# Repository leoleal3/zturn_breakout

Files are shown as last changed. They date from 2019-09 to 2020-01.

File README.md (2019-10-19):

# zturn_breakout
A custom breakout board for the MYIR Z-Turn single board computer

### v1.0 - Full Breakout Board for Z-Turn
Status: Complete!   
Dimensions: 5.2"x4.5"   
Board Features:  
* 9 2x6 PMOD connectors
* 1 1x6 PMOD connector
* 2mm JTAG connector

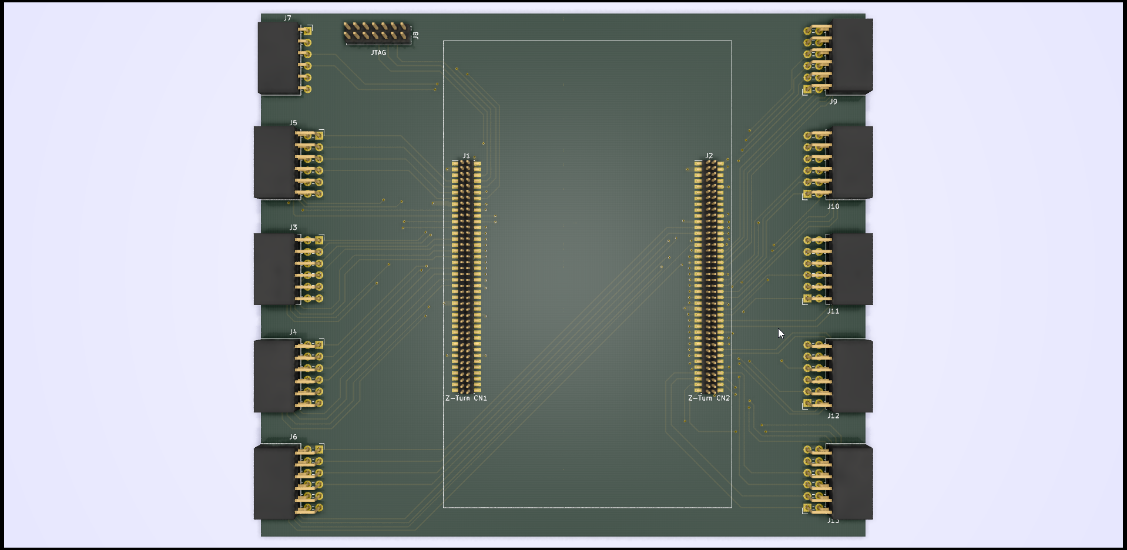
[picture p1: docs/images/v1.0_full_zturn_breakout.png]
KiCAD Render of Full Breakout Board


### v0.1 - Digilent HS3 JTAG Cable Adapter (2.54mm to 2mm)
Status: Complete!   
This is a simple 2.54mm to 2mm connector adapter to allow the use of the much cheaper [HS3 JTAG cable from Digilent](https://store.digilentinc.com/jtag-hs3-programming-cable/)

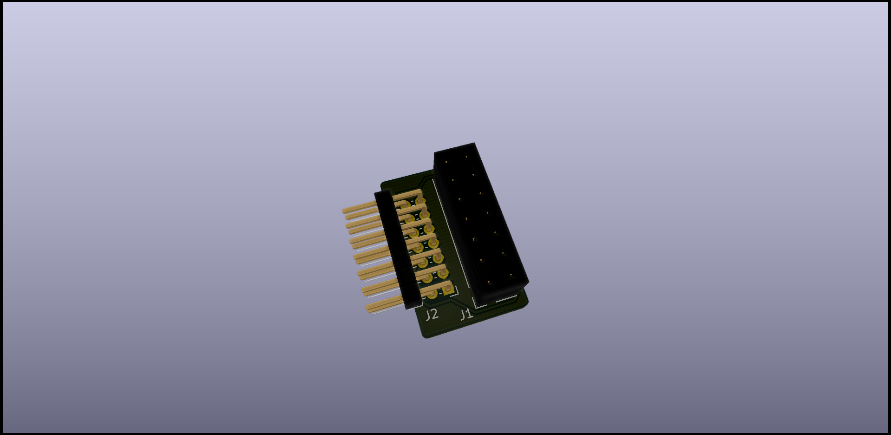
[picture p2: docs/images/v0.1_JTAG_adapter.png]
KiCAD Render of JTAG Adapter


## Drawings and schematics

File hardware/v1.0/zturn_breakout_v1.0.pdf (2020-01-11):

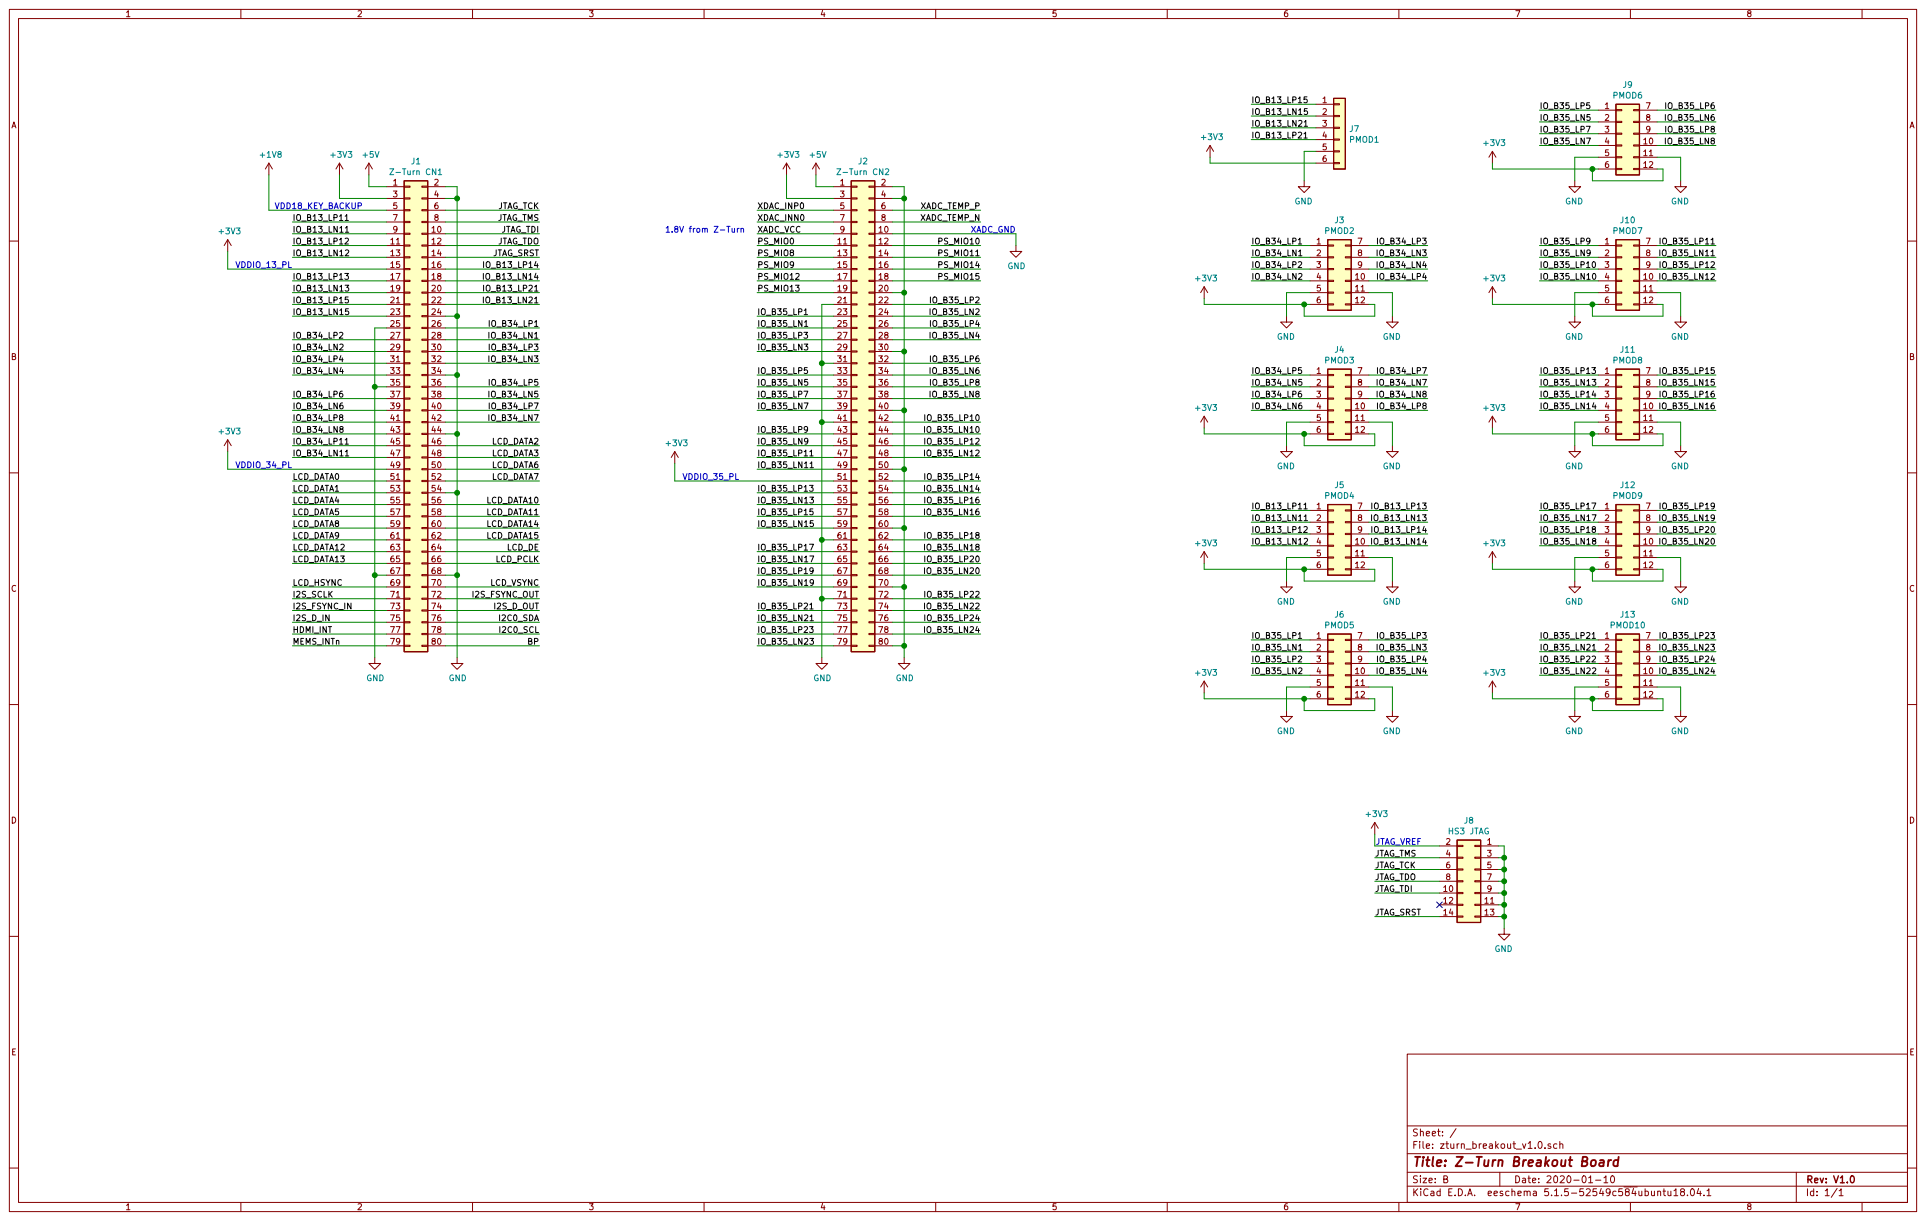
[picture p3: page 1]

File: zturn_breakout_v1.0.sch Sheet: /
Id: 1/1 Title: Z-Turn Breakout Board

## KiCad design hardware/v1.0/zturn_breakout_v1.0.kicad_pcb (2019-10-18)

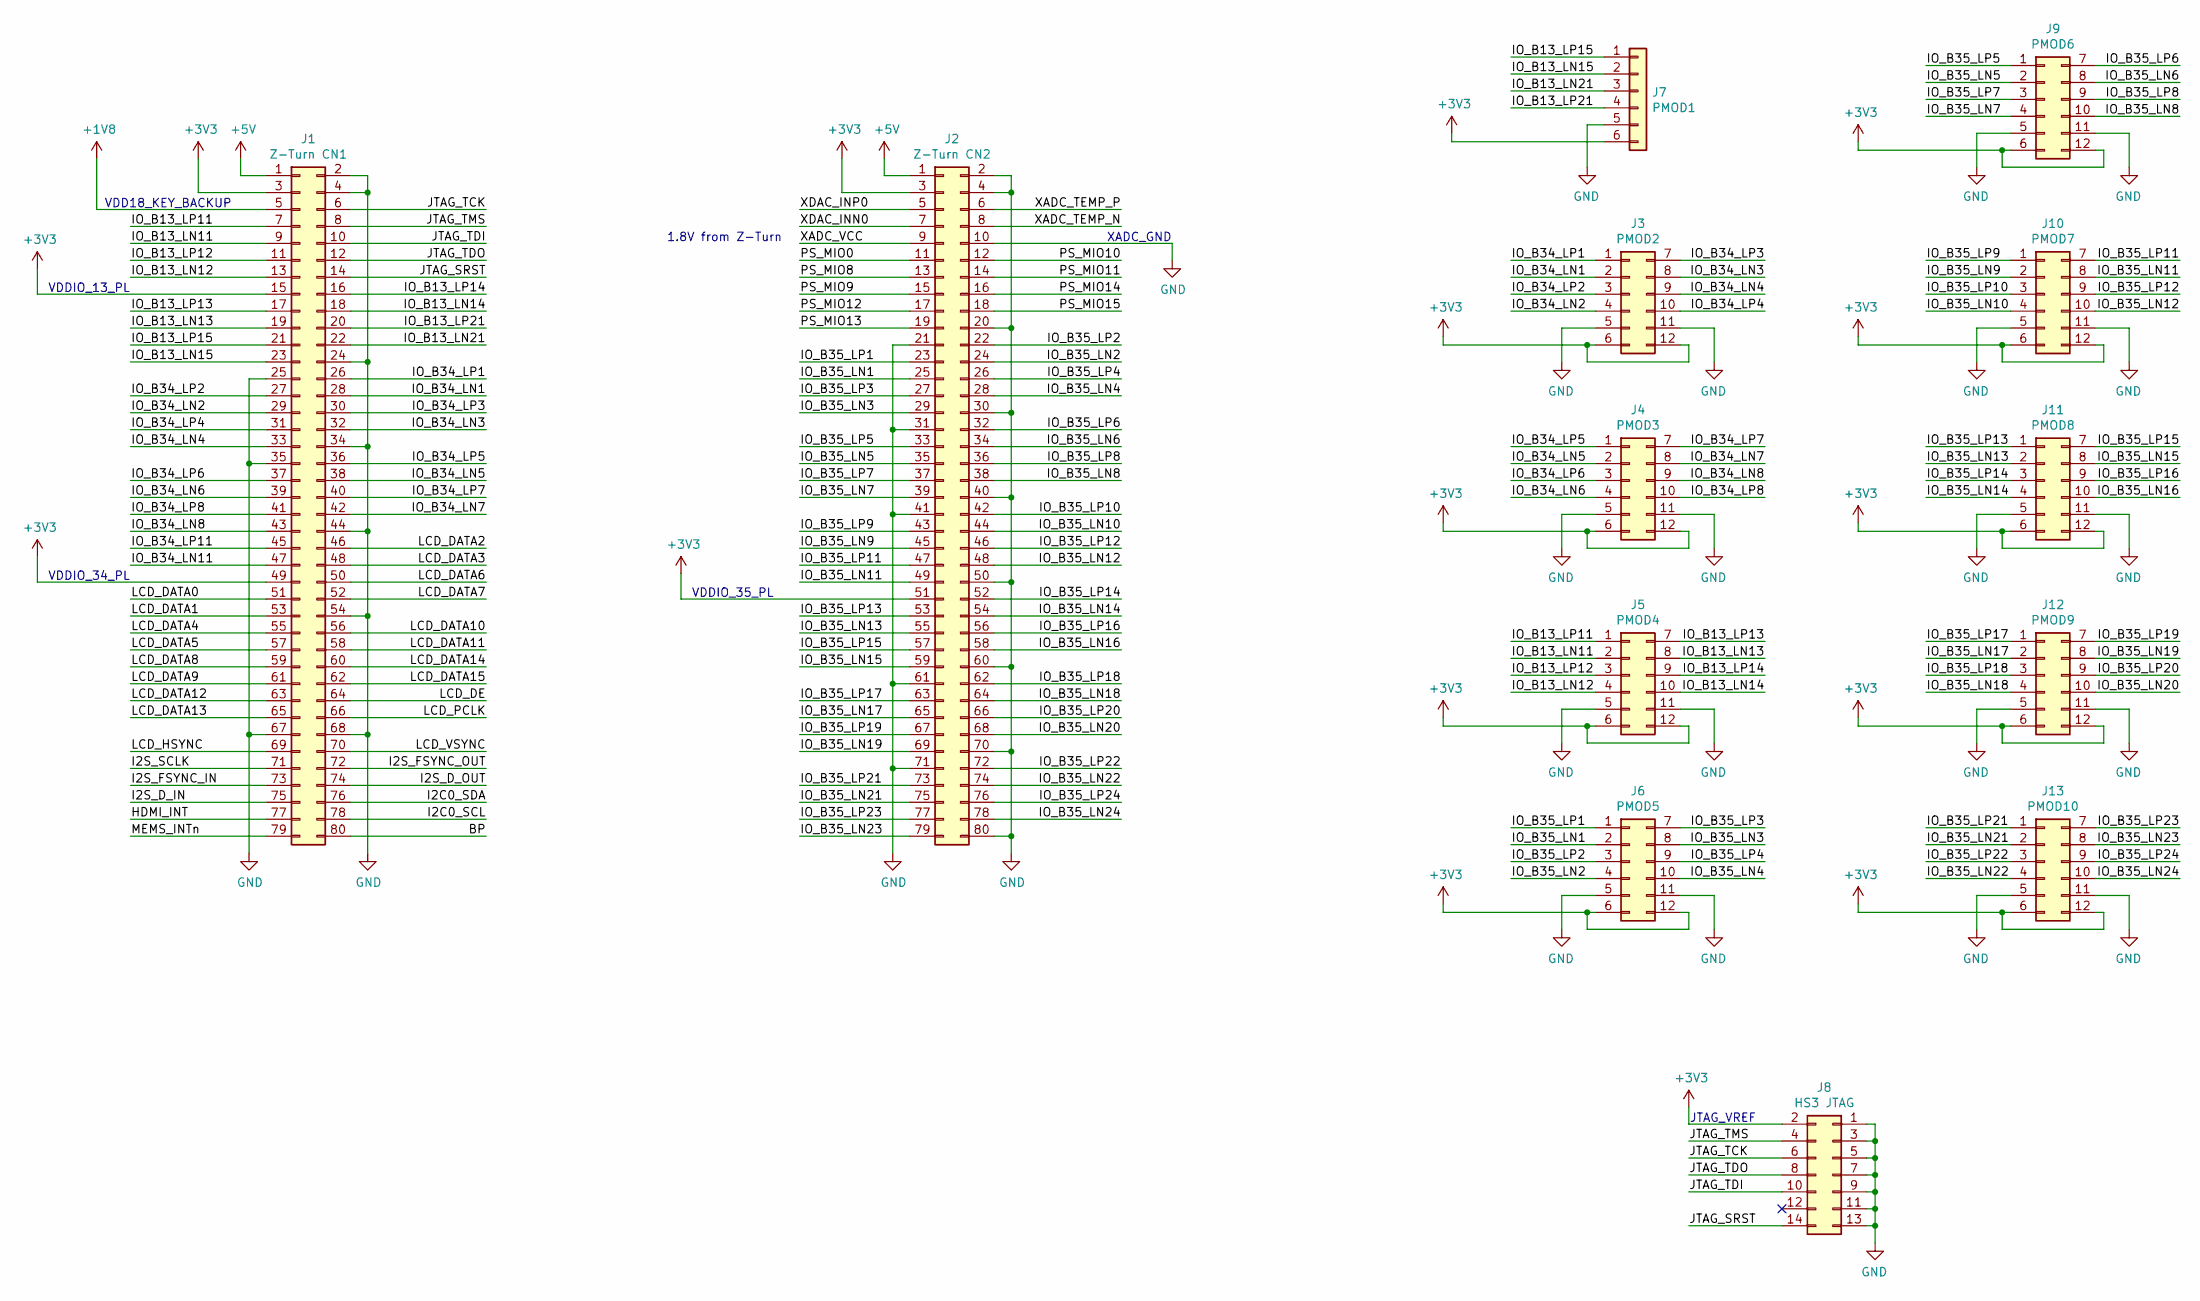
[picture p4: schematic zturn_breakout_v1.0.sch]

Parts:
J1: Z-Turn CN1; PinHeader_2x40_P1.27mm_Vertical_SMD; MPN 20021111-00080T4LF
J2: Z-Turn CN2; PinHeader_2x40_P1.27mm_Vertical_SMD; MPN 20021111-00080T4LF
J3: PMOD2; PinSocket_2x06_P2.54mm_Horizontal
J4: PMOD3; PinSocket_2x06_P2.54mm_Horizontal
J5: PMOD4; PinSocket_2x06_P2.54mm_Horizontal
J6: PMOD5; PinSocket_2x06_P2.54mm_Horizontal
J7: PMOD1; PinSocket_1x06_P2.54mm_Horizontal
J8: HS3 JTAG; PinHeader_2x07_P2.00mm_Vertical
J9: PMOD6; PinSocket_2x06_P2.54mm_Horizontal
J10: PMOD7; PinSocket_2x06_P2.54mm_Horizontal
J11: PMOD8; PinSocket_2x06_P2.54mm_Horizontal
J12: PMOD9; PinSocket_2x06_P2.54mm_Horizontal
J13: PMOD10; PinSocket_2x06_P2.54mm_Horizontal

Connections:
+1V8: J1.5
+3V3: J1.3, J1.15, J1.49, J2.3, J2.51, J3.6, J3.12, J4.6, J4.12, J5.6, J5.12, J6.6, J6.12, J7.6, J8.2, J9.6, J9.12, J10.6, J10.12, J11.6, J11.12, J12.6, J12.12, J13.6, J13.12
+5V: J1.1, J2.1
/BP: J1.80
/HDMI_INT: J1.77
/I2C0_SCL: J1.78
/I2C0_SDA: J1.76
/I2S_D_IN: J1.75
/I2S_D_OUT: J1.74
/I2S_FSYNC_IN: J1.73
/I2S_FSYNC_OUT: J1.72
/I2S_SCLK: J1.71
/IO_B13_LN11: J1.9, J5.2
/IO_B13_LN12: J1.13, J5.4
/IO_B13_LN13: J1.19, J5.8
/IO_B13_LN14: J1.18, J5.10
/IO_B13_LN15: J1.23, J7.2
/IO_B13_LN21: J1.22, J7.3
/IO_B13_LP11: J1.7, J5.1
/IO_B13_LP12: J1.11, J5.3
/IO_B13_LP13: J1.17, J5.7
/IO_B13_LP14: J1.16, J5.9
/IO_B13_LP15: J1.21, J7.1
/IO_B13_LP21: J1.20, J7.4
/IO_B34_LN1: J1.28, J3.2
/IO_B34_LN2: J1.29, J3.4
/IO_B34_LN3: J1.32, J3.8
/IO_B34_LN4: J1.33, J3.9
/IO_B34_LN5: J1.38, J4.2
/IO_B34_LN6: J1.39, J4.4
/IO_B34_LN7: J1.42, J4.8
/IO_B34_LN8: J1.43, J4.9
/IO_B34_LN11: J1.47
/IO_B34_LP1: J1.26, J3.1
/IO_B34_LP2: J1.27, J3.3
/IO_B34_LP3: J1.30, J3.7
/IO_B34_LP4: J1.31, J3.10
/IO_B34_LP5: J1.36, J4.1
/IO_B34_LP6: J1.37, J4.3
/IO_B34_LP7: J1.40, J4.7
/IO_B34_LP8: J1.41, J4.10
/IO_B34_LP11: J1.45
/IO_B35_LN1: J2.25, J6.2
/IO_B35_LN2: J2.24, J6.4
/IO_B35_LN3: J2.29, J6.8
/IO_B35_LN4: J2.28, J6.10
/IO_B35_LN5: J2.35, J9.2
/IO_B35_LN6: J2.34, J9.8
/IO_B35_LN7: J2.39, J9.4
/IO_B35_LN8: J2.38, J9.10
/IO_B35_LN9: J2.45, J10.2
/IO_B35_LN10: J2.44, J10.4
/IO_B35_LN11: J2.49, J10.8
/IO_B35_LN12: J2.48, J10.10
/IO_B35_LN13: J2.55, J11.2
/IO_B35_LN14: J2.54, J11.4
/IO_B35_LN15: J2.59, J11.8
/IO_B35_LN16: J2.58, J11.10
/IO_B35_LN17: J2.65, J12.2
/IO_B35_LN18: J2.64, J12.4
/IO_B35_LN19: J2.69, J12.8
/IO_B35_LN20: J2.68, J12.10
/IO_B35_LN21: J2.75, J13.2
/IO_B35_LN22: J2.74, J13.4
/IO_B35_LN23: J2.79, J13.8
/IO_B35_LN24: J2.78, J13.10
/IO_B35_LP1: J2.23, J6.1
/IO_B35_LP2: J2.22, J6.3
/IO_B35_LP3: J2.27, J6.7
/IO_B35_LP4: J2.26, J6.9
/IO_B35_LP5: J2.33, J9.1
/IO_B35_LP6: J2.32, J9.7
/IO_B35_LP7: J2.37, J9.3
/IO_B35_LP8: J2.36, J9.9
/IO_B35_LP9: J2.43, J10.1
/IO_B35_LP10: J2.42, J10.3
/IO_B35_LP11: J2.47, J10.7
/IO_B35_LP12: J2.46, J10.9
/IO_B35_LP13: J2.53, J11.1
/IO_B35_LP14: J2.52, J11.3
/IO_B35_LP15: J2.57, J11.7
/IO_B35_LP16: J2.56, J11.9
/IO_B35_LP17: J2.63, J12.1
/IO_B35_LP18: J2.62, J12.3
/IO_B35_LP19: J2.67, J12.7
/IO_B35_LP20: J2.66, J12.9
/IO_B35_LP21: J2.73, J13.1
/IO_B35_LP22: J2.72, J13.3
/IO_B35_LP23: J2.77, J13.7
/IO_B35_LP24: J2.76, J13.9
/JTAG_SRST: J1.14, J8.14
/JTAG_TCK: J1.6, J8.6
/JTAG_TDI: J1.10, J8.10
/JTAG_TDO: J1.12, J8.8
/JTAG_TMS: J1.8, J8.4
/LCD_DATA0: J1.51
/LCD_DATA1: J1.53
/LCD_DATA2: J1.46
/LCD_DATA3: J1.48
/LCD_DATA4: J1.55
/LCD_DATA5: J1.57
/LCD_DATA6: J1.50
/LCD_DATA7: J1.52
/LCD_DATA8: J1.59
/LCD_DATA9: J1.61
/LCD_DATA10: J1.56
/LCD_DATA11: J1.58
/LCD_DATA12: J1.63
/LCD_DATA13: J1.65
/LCD_DATA14: J1.60
/LCD_DATA15: J1.62
/LCD_DE: J1.64
/LCD_HSYNC: J1.69
/LCD_PCLK: J1.66
/LCD_VSYNC: J1.70
/MEMS_INTn: J1.79
/PS_MIO0: J2.11
/PS_MIO8: J2.13
/PS_MIO9: J2.15
/PS_MIO10: J2.12
/PS_MIO11: J2.14
/PS_MIO12: J2.17
/PS_MIO13: J2.19
/PS_MIO14: J2.16
/PS_MIO15: J2.18
/XADC_TEMP_N: J2.8
/XADC_TEMP_P: J2.6
/XADC_VCC: J2.9
/XDAC_INN0: J2.7
/XDAC_INP0: J2.5
GND: J1.2, J1.4, J1.24, J1.25, J1.34, J1.35, J1.44, J1.54, J1.67, J1.68, J2.2, J2.4, J2.10, J2.20, J2.21, J2.30, J2.31, J2.40, J2.41, J2.50, J2.60, J2.61, J2.70, J2.71, J2.80, J3.5, J3.11, J4.5, J4.11, J5.5, J5.11, J6.5, J6.11, J7.5, J8.1, J8.3, J8.5, J8.7, J8.9, J8.11, J8.13, J9.5, J9.11, J10.5, J10.11, J11.5, J11.11, J12.5, J12.11, J13.5, J13.11

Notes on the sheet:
XADC_GND
VDDIO_13_PL
VDDIO_34_PL
VDDIO_35_PL
VDD18_KEY_BACKUP
1.8V from Z-Turn
JTAG_VREF

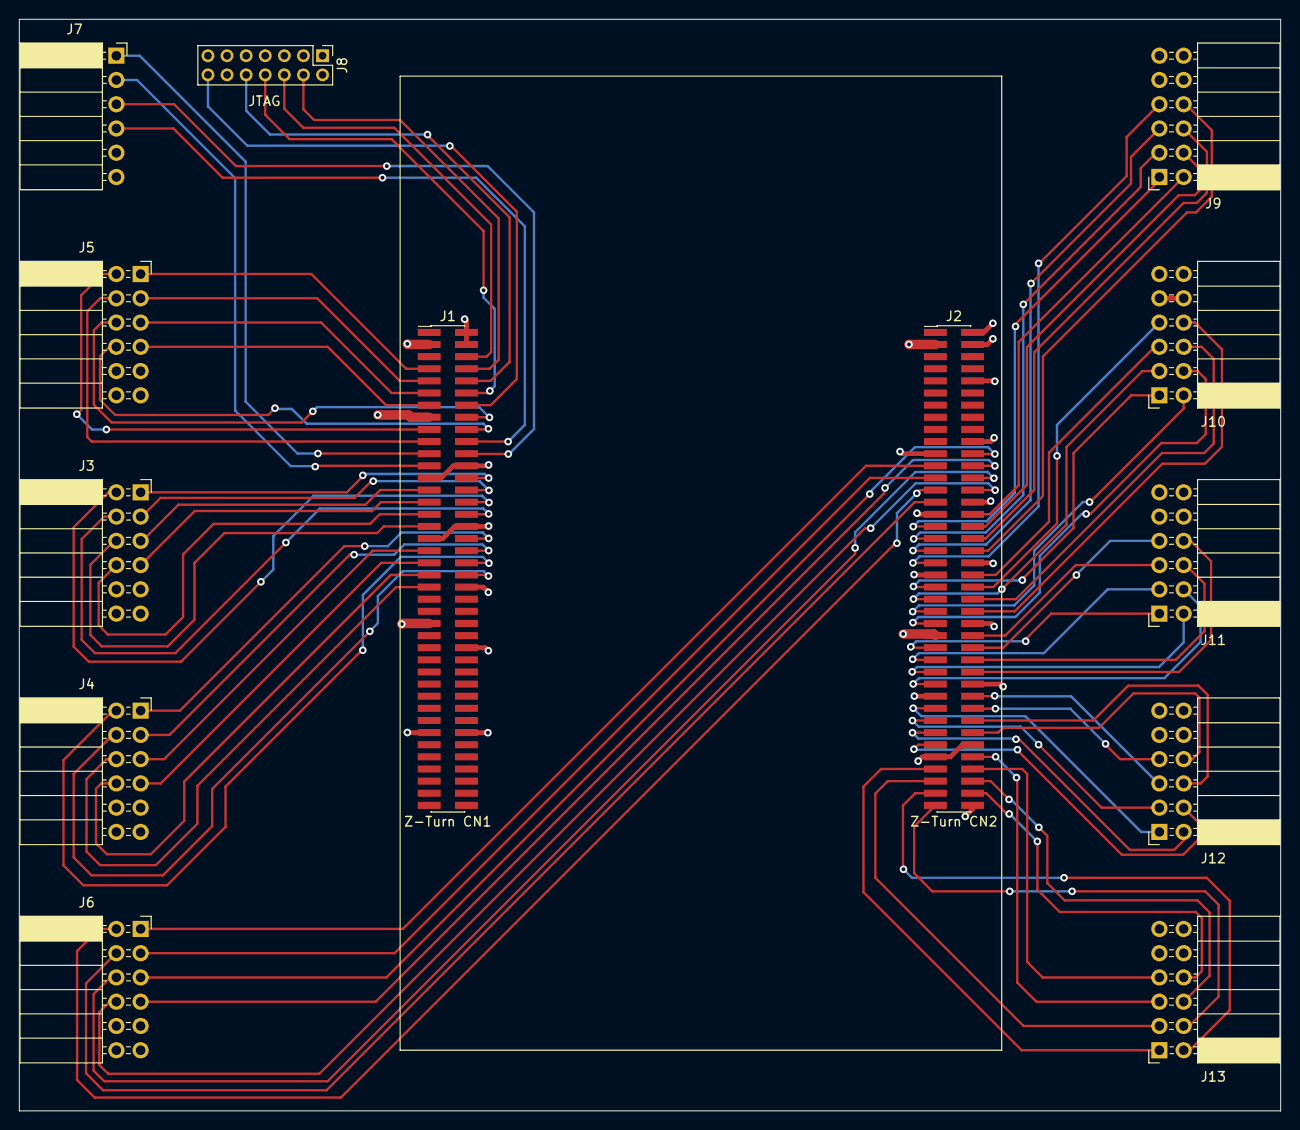
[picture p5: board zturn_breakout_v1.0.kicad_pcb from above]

Board: 4 copper layers, 132.1 x 114.3 mm, 13 parts (0 on the bottom side), 84 nets.

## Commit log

2019-09-12 Initial commit of v0.1 PCB, HS3 JTAG adapter
    [zturn_breakout-B_Cu.gbr, zturn_breakout-B_Mask.gbr, zturn_breakout-B_Paste.gbr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]
2019-09-21 Cleaned up v0.1 and began v1.0 schematic
    [zturn_breakout.kicad_pcb, zturn_breakout.sch, zturn_breakout_v1.0.kicad_pcb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]
2019-10-18 Completed schematic and layout of v1.0
    [zturn_breakout_v1.0.kicad_pcb, zturn_breakout_v1.0.sch]
2019-10-18 Added board render images
2020-01-11 Added pdf schematic
    [zturn_breakout_v1.0.sch]
